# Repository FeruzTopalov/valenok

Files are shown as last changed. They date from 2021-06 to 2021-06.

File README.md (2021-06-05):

## **VALENOK** - yet another DS18B20 thermometer, but...

<p align="center">
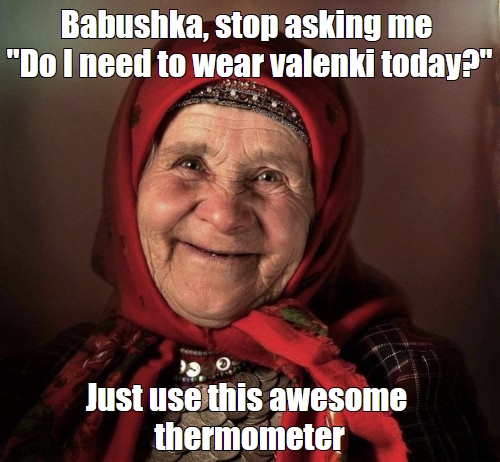
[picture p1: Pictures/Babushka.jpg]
  
  <br>
  <a href="https://youtu.be/WqwGhjjpDnw">https://youtu.be/WqwGhjjpDnw</a>
</p>

* Eyes-friendly static indication
* Zero-consumption when IDLE, years without battery replacement
* Single button interface
* Only temperature - who the f**k needs more?
* Totally open-source/open-hardware
* Easy solderable - 0805 chip components and huuuge SMD packages

## Hardware

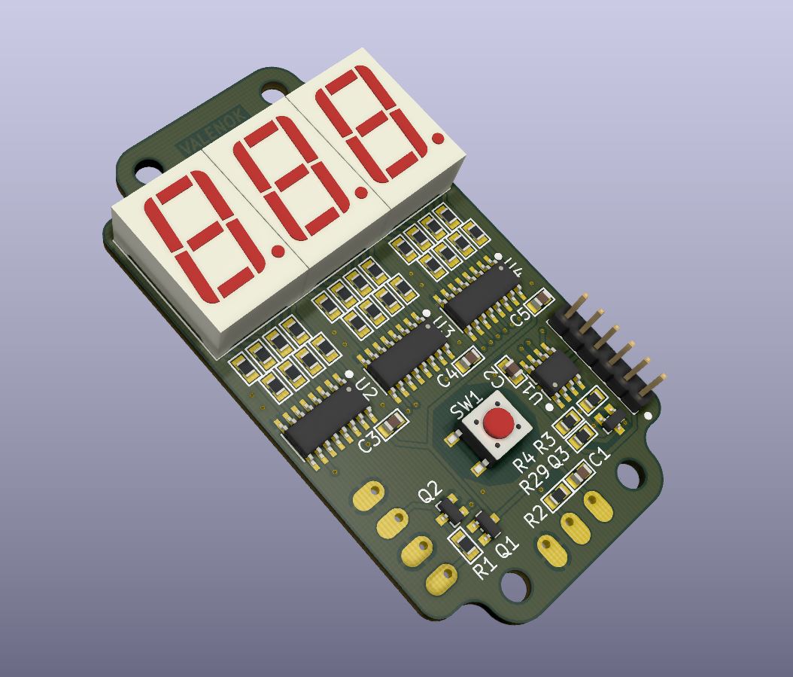
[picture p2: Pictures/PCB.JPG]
PCB


Well, it is a typical KiCad project, schematic + PCB. Also there are prepared gerbers, so if you don't want to deal with KiCad, just zip "gerbers" folder and send it to your PCB supplier. 

Schematic is pretty simple. Q1 and Q2 are power switch, which is controlled via MCU. Q3 is a "HC595 anti-glitch" which controls the sift registers state at power-up. By the way, switch SW1 powers on the thermometer, after that MCU holds Q2's gate until the end of the program.

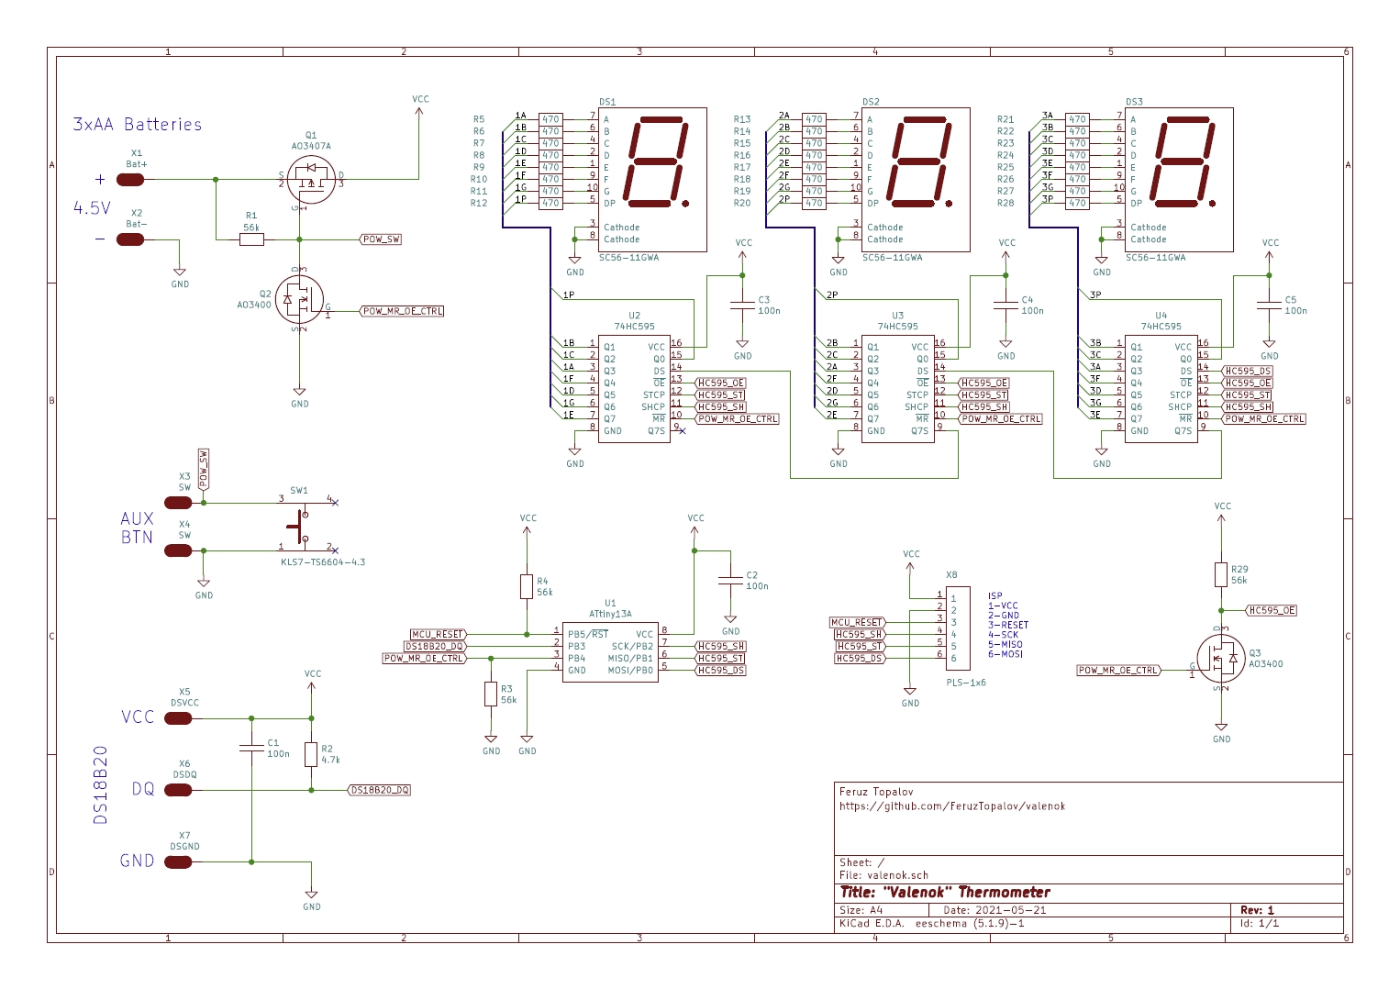
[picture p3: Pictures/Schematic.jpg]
Schematic


As you can see, power switch and shift registers are controlled using common pin PB4 (POW_MR_OE_CTRL). That trick is here in order to clear the shift registers (HC595) at startup. The algorithm is following:

* User pushes the SW1
* PB4 is low, power is not engaged by Q2
* OE is high due to inversion at the Q3, outputs of the shift registers are in Hi-Z
* MR is low, shift registers are cleared
* Firmware strikes a strobe to the shift registers ST inputs, the content of the shift registers (which are empty) are copied to the outputs
* Finally, MCU rise up PB4, engage the power switch and enables the shift registers outputs
* You see empty 7-seg display, no randomly blinking segments anymore... PROFIT!

_See 'Pictures/Trick.jpg' for details_

## Firmware

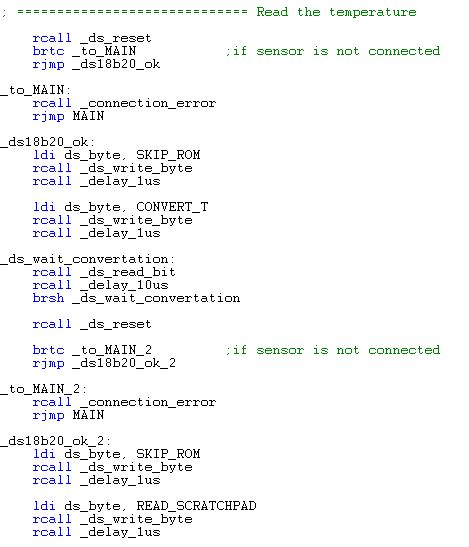
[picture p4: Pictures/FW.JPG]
FW


Written in assembler using pretty old AVR Studio 4.19, therefore i publish only the listing but not the project file. I you want to compile by yourself, use any appropriate AVR compiler or find AVR Studio 4.19 on the internet. Anyway there is a ready .hex file to flash.

Firmware flow:
* Clear HC595 registers
* Hold the power
* Blink all segments for 100 ms in order to check their functionality
* Check sensor presence, show "---" if not connected
* Read the temperature
* Calculate CRC, show "crc" if mismatch
* Check DS18B20 for 12-bit mode, if not then switch to 12-bit mode
* Perform temperature rounding +-0.5 Celsius degree
* Prepare display content and show
* Hold on for 3 sec
* Release the power

Flashing is also simple, the only thing you should aware is that you have to change fuse bits. Tiny13A's factory default fuses are LOW:0x6A; HIGH:0xFF. To make thermometer works it is only needed to switch off internal clock division by 8 (CKDIV8). Therefore only LOW fuse is affected, it's value changes from LOW:0x6A to LOW:0x7A - that simple. I recommend to use AVRDUDESS (https://github.com/zkemble/AVRDUDESS). 

## Enclosure

It is designed to be placed in a market available GAINTA G1068G/G1068B enclosure. It has dimensions of 95 x 48 x 38 mm. 

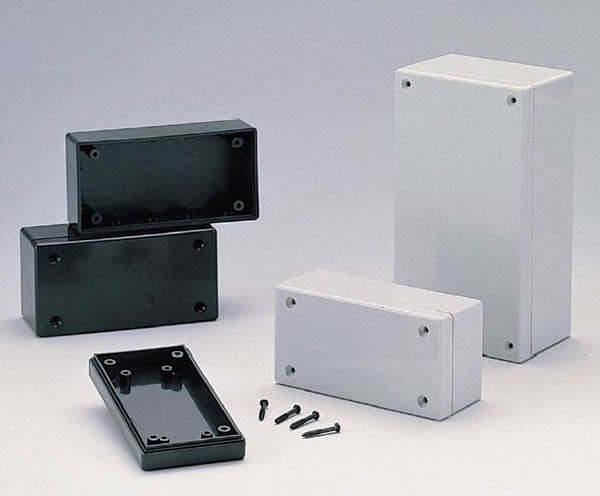
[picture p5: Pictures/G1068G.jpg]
Enclosure


PCB is fixed to the smaller lid using 20 mm Male-Female Hex standoffs; 3x AA batteries with no holder are placed underneath the PCB.

In "dxf" folder you can find a guide where to make holes - one for 7-Seg display, one for button:

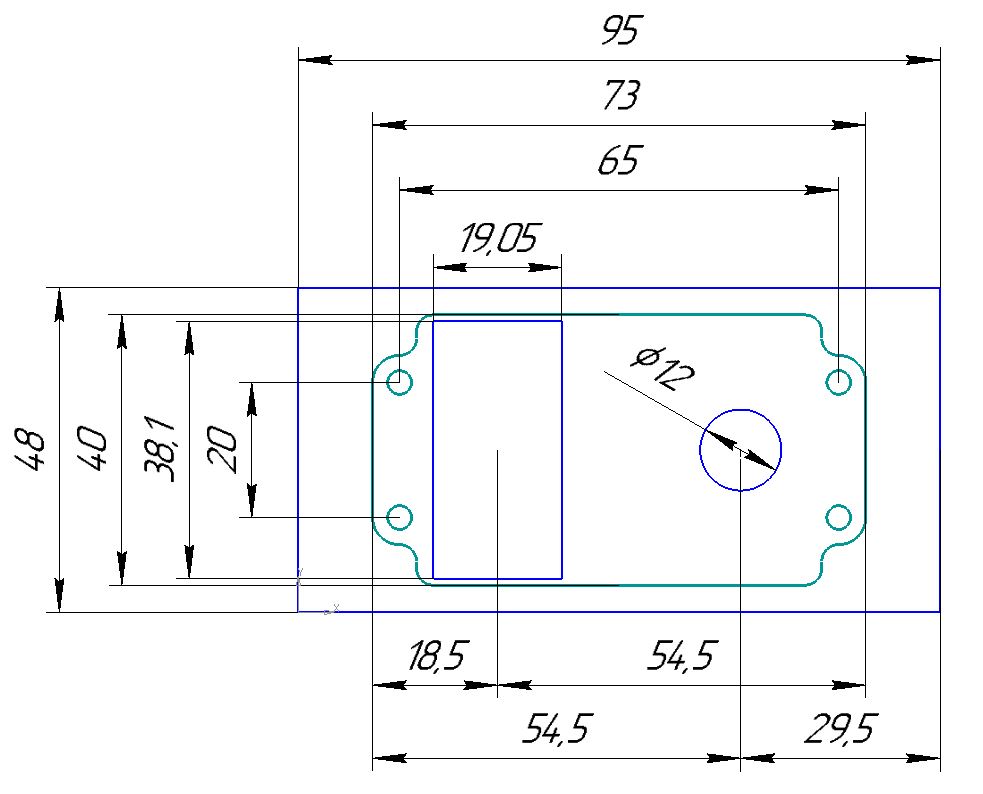
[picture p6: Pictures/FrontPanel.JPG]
Panel


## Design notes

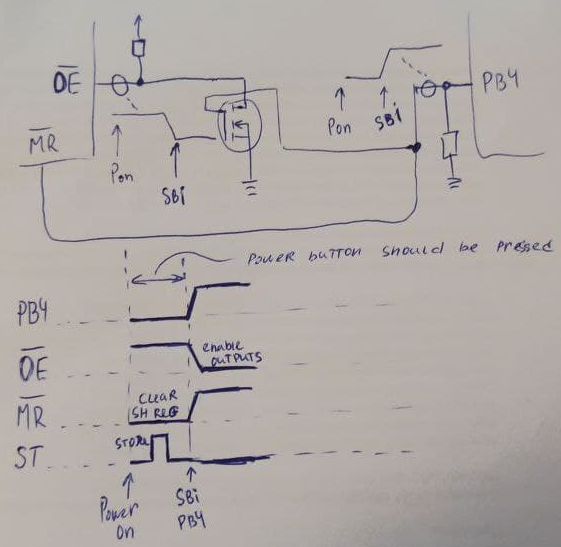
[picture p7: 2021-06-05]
Pictures/Trick.jpg

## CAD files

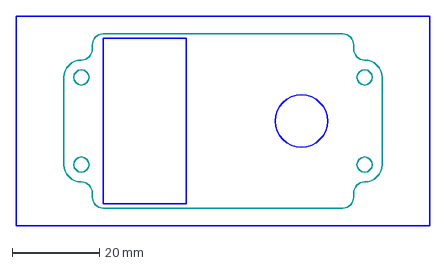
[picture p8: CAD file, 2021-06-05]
Hardware/dxf/PCB_over_front_panel.dxf
95.0 x 48.0 mm

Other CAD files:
Hardware/dxf/G1068B_G1068B.dwg

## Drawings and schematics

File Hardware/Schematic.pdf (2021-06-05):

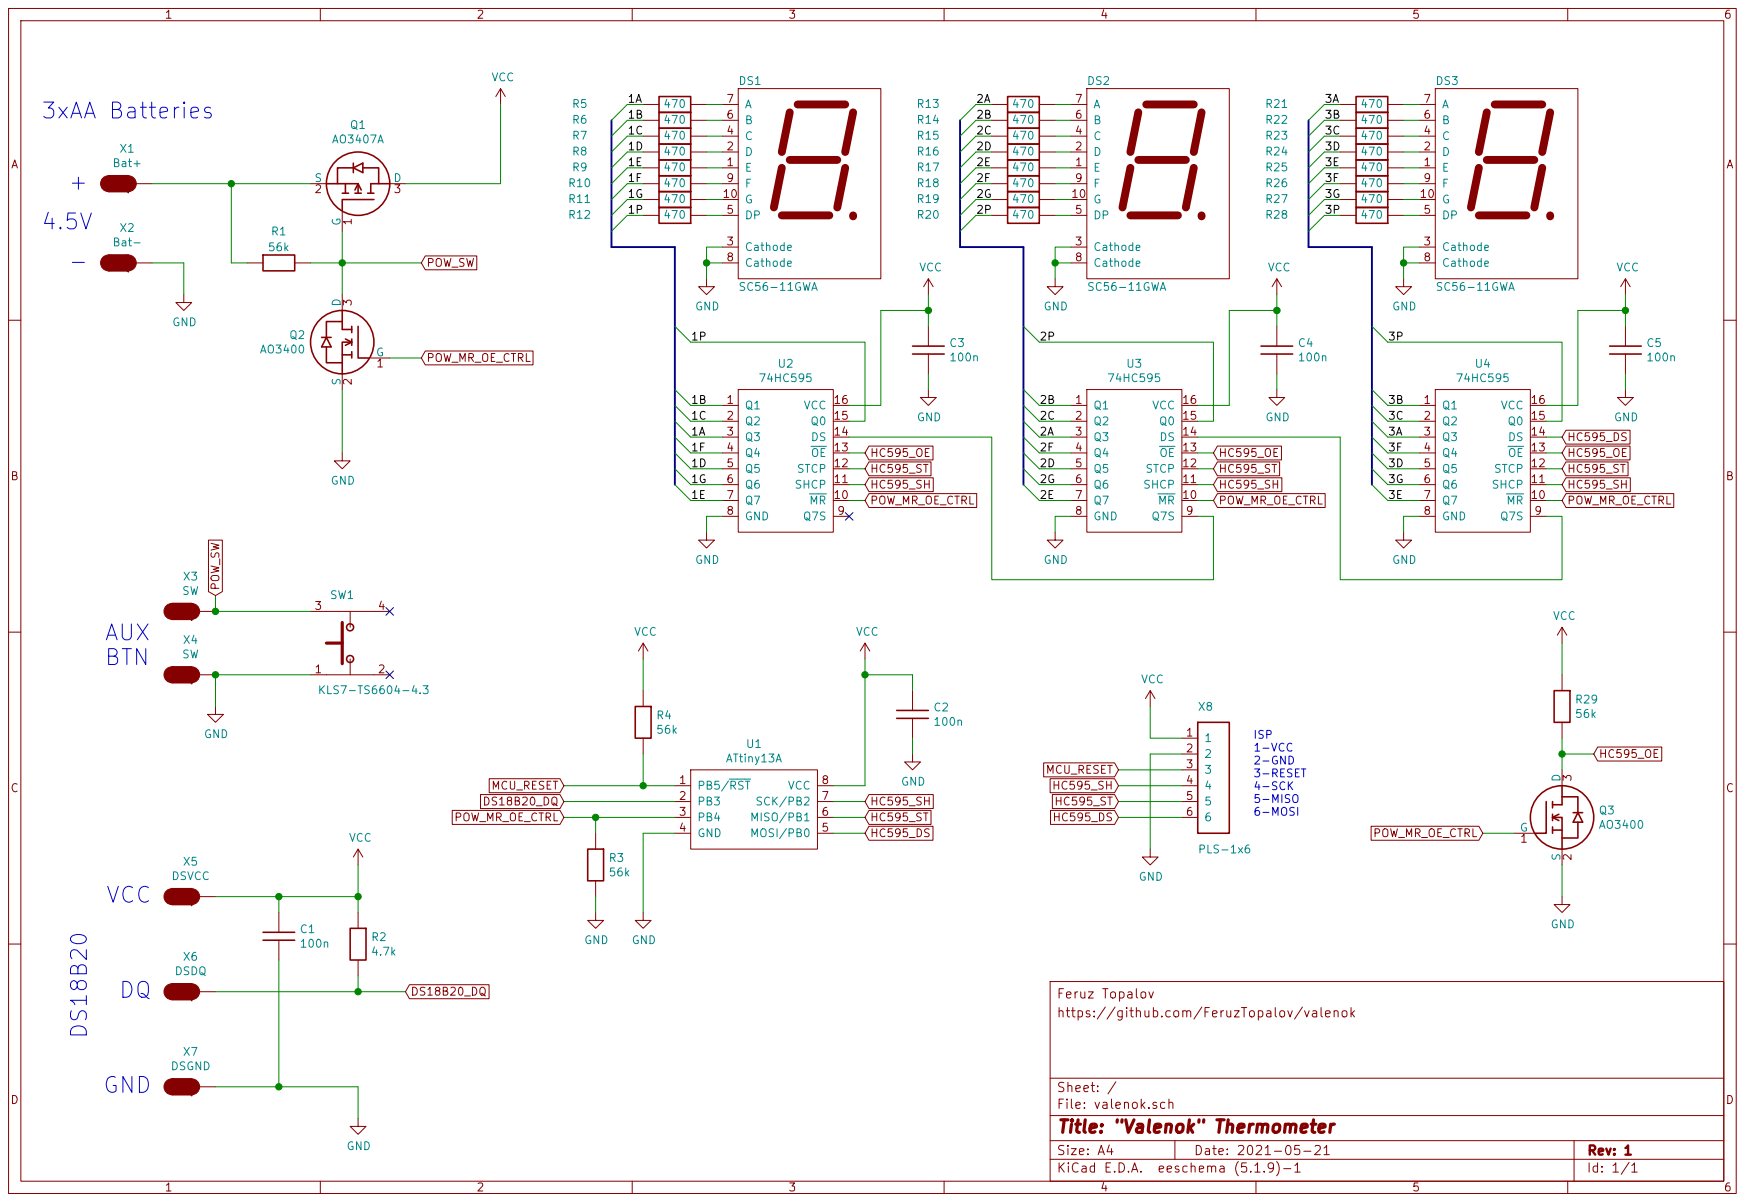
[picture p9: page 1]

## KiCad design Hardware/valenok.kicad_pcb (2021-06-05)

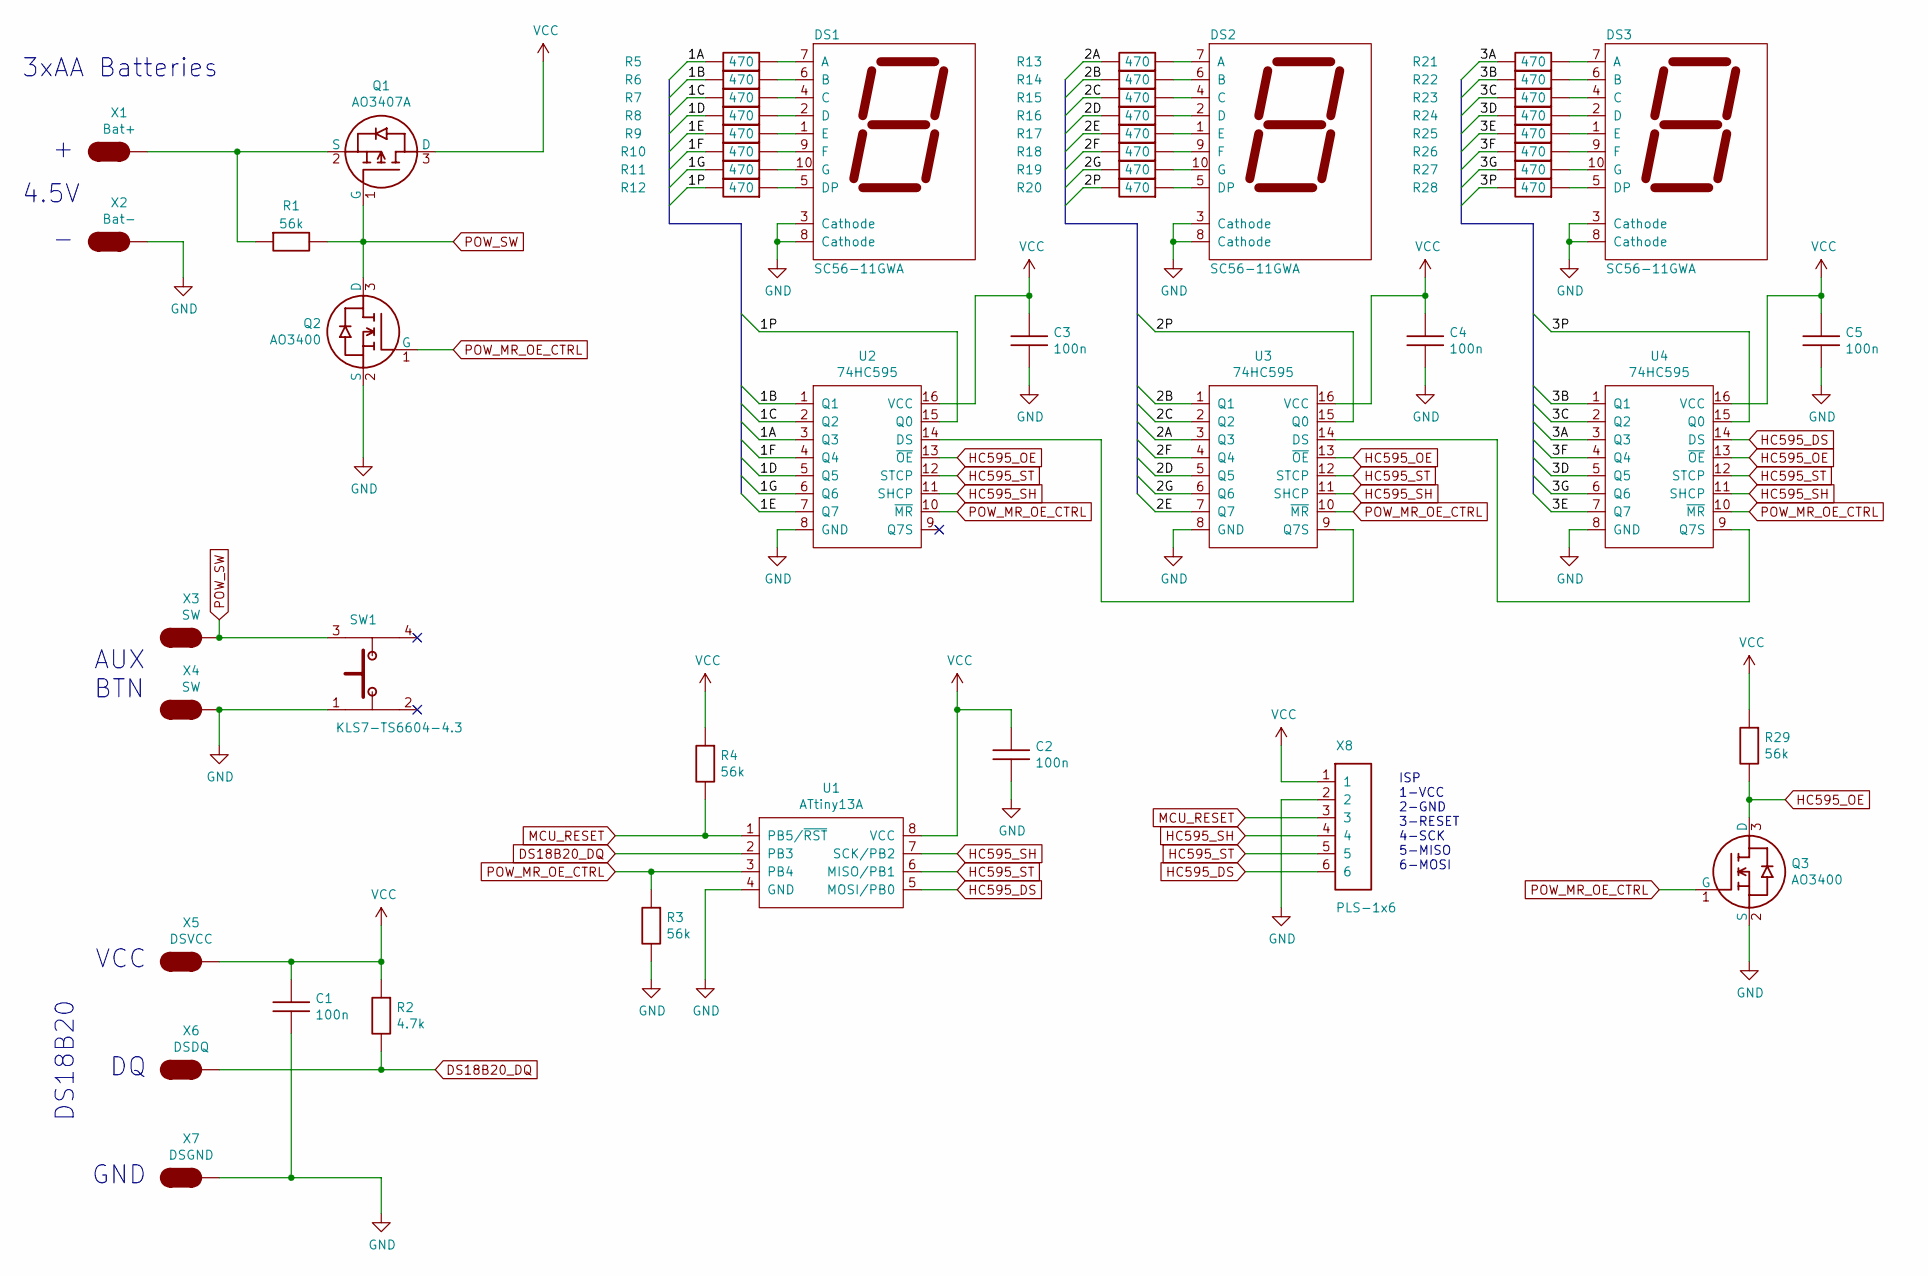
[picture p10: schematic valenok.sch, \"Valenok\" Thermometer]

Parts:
C1, C2, C3, C4, C5: 100n; C0805
DS1, DS2, DS3: SC56-11GWA; 7seg_0.56in
Q1: AO3407A; SOT-23
Q2, Q3: AO3400; SOT-23
R1, R3, R4, R29: 56k; R0805
R2: 4.7k; R0805
R5, R6, R7, R8, R9, R10, R11, R12, R13, R14, R15, R16, R17, R18, R19, R20, R21, R22, R23, R24, R25, R26, R27, R28: 470; R0805
SW1: KLS7-TS6604-4.3; 6x6switch
U1: ATtiny13A; SOIC-8
U2, U3, U4: 74HC595; SOIC-16
X1: Bat+; Pad
X2: Bat-; Pad
X3, X4: SW; Pad
X5: DSVCC; Pad
X6: DSDQ; Pad
X7: DSGND; Pad
X8: PLS-1x6; 1x6header

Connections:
/1A: R5.2, U2.3 (Q3)
/1B: R6.2, U2.1 (Q1)
/1C: R7.2, U2.2 (Q2)
/1D: R8.2, U2.5 (Q5)
/1E: R9.2, U2.7 (Q7)
/1F: R10.2, U2.4 (Q4)
/1G: R11.2, U2.6 (Q6)
/1P: R12.2, U2.15 (Q0)
/2A: R13.2, U3.3 (Q3)
/2B: R14.2, U3.1 (Q1)
/2C: R15.2, U3.2 (Q2)
/2D: R16.2, U3.5 (Q5)
/2E: R17.2, U3.7 (Q7)
/2F: R18.2, U3.4 (Q4)
/2G: R19.2, U3.6 (Q6)
/2P: R20.2, U3.15 (Q0)
/3A: R21.2, U4.3 (Q3)
/3B: R22.2, U4.1 (Q1)
/3C: R23.2, U4.2 (Q2)
/3D: R24.2, U4.5 (Q5)
/3E: R25.2, U4.7 (Q7)
/3F: R26.2, U4.4 (Q4)
/3G: R27.2, U4.6 (Q6)
/3P: R28.2, U4.15 (Q0)
DS18B20_DQ: R2.2, U1.2 (PB3), X6.1
GND: C1.2, C2.2, C3.2, C4.2, C5.2, DS1.3 (Cathode), DS1.8 (Cathode), DS2.3 (Cathode), DS2.8 (Cathode), DS3.3 (Cathode), DS3.8 (Cathode), Q2.2 (S), Q3.2 (S), R3.2, SW1.1, U1.4 (GND), U2.8 (GND), U3.8 (GND), U4.8 (GND), X2.1, X4.1, X7.1, X8.2
HC595_DS: U1.5 (MOSI/PB0), U4.14 (DS), X8.6
HC595_OE: Q3.3 (D), R29.2, U2.13 (~OE), U3.13 (~OE), U4.13 (~OE)
HC595_SH: U1.7 (SCK/PB2), U2.11 (SHCP), U3.11 (SHCP), U4.11 (SHCP), X8.4
HC595_ST: U1.6 (MISO/PB1), U2.12 (STCP), U3.12 (STCP), U4.12 (STCP), X8.5
MCU_RESET: R4.2, U1.1 (PB5/~RST), X8.3
unnamed: DS1.1 (E), R9.1
unnamed: DS1.2 (D), R8.1
unnamed: DS1.4 (C), R7.1
unnamed: DS1.5 (DP), R12.1
unnamed: DS1.6 (B), R6.1
unnamed: DS1.7 (A), R5.1
unnamed: DS1.9 (F), R10.1
unnamed: DS1.10 (G), R11.1
unnamed: DS2.1 (E), R17.1
unnamed: DS2.2 (D), R16.1
unnamed: DS2.4 (C), R15.1
unnamed: DS2.5 (DP), R20.1
unnamed: DS2.6 (B), R14.1
unnamed: DS2.7 (A), R13.1
unnamed: DS2.9 (F), R18.1
unnamed: DS2.10 (G), R19.1
unnamed: DS3.1 (E), R25.1
unnamed: DS3.2 (D), R24.1
unnamed: DS3.4 (C), R23.1
unnamed: DS3.5 (DP), R28.1
unnamed: DS3.6 (B), R22.1
unnamed: DS3.7 (A), R21.1
unnamed: DS3.9 (F), R26.1
unnamed: DS3.10 (G), R27.1
unnamed: Q1.2 (S), R1.1, X1.1
unnamed: U2.14 (DS), U3.9 (Q7S)
unnamed: U3.14 (DS), U4.9 (Q7S)
POW_MR_OE_CTRL: Q2.1 (G), Q3.1 (G), R3.1, U1.3 (PB4), U2.10 (~MR), U3.10 (~MR), U4.10 (~MR)
POW_SW: Q1.1 (G), Q2.3 (D), R1.2, SW1.3, X3.1
VCC: C1.1, C2.1, C3.1, C4.1, C5.1, Q1.3 (D), R2.1, R4.1, R29.1, U1.8 (VCC), U2.16 (VCC), U3.16 (VCC), U4.16 (VCC), X5.1, X8.1

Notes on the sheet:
4.5V
AUX BTN
DS18B20
GND
VCC
ISP 1-VCC 2-GND 3-RESET 4-SCK 5-MISO 6-MOSI
3xAA Batteries

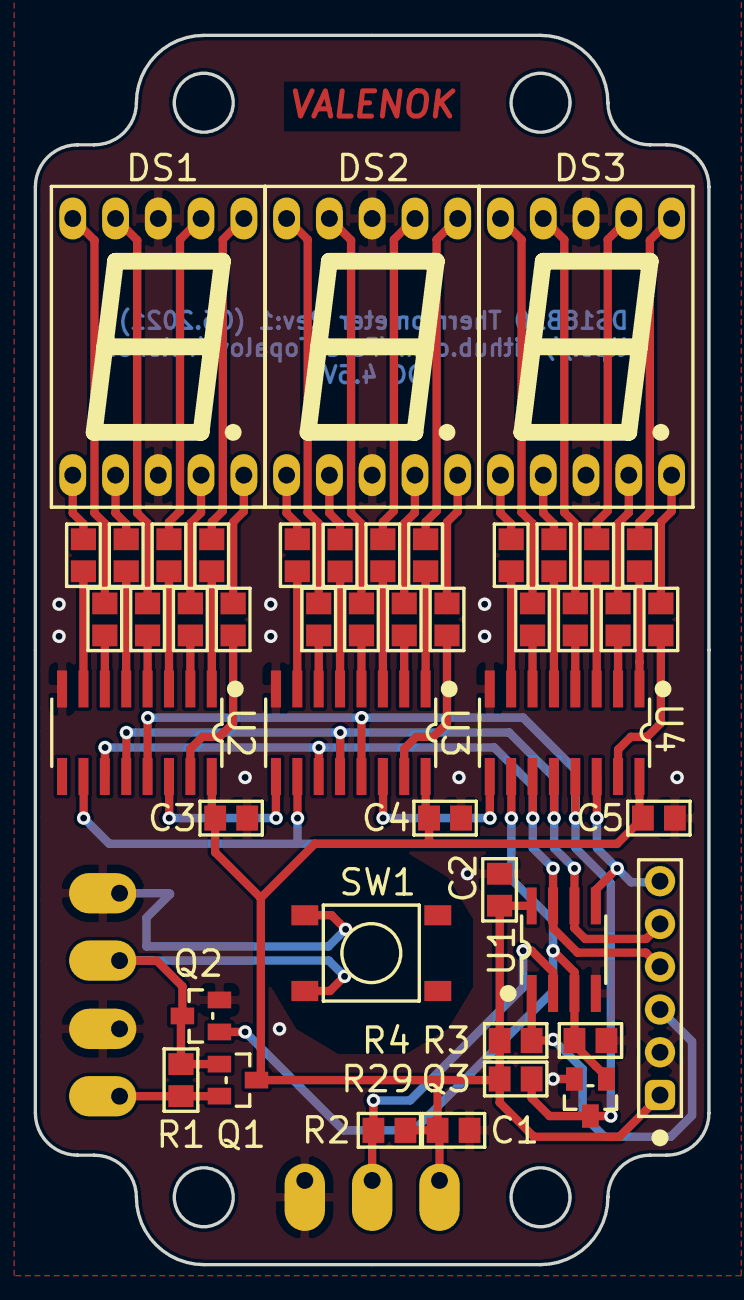
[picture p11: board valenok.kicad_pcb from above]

Board: 2 copper layers, 40.0 x 73.0 mm, 53 parts (0 on the bottom side), 61 nets.

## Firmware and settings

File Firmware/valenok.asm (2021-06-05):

;	Valenok - Simple and affordable DS18B20-based thermometer in a Gainta G1068G case written in AVR Assembly
;	<https://github.com/FeruzTopalov/valenok/>
;	Copyright (C) 2021 Feruz Topalov
;	Released under the GNU General Public License v3.0 <https://www.gnu.org/licenses/>
;    
;	File: valenok.asm
;	Compiler: AVR Studio 4.19
;	
;	Fuses for AVRDUDESS: LOW:0x7A; HIGH:0xFF (internal RC 9.6 MHz, no clock division)

						

; =============================	Include

.include  "tn13Adef.inc"

; =============================	DS18B20 macroses

	.macro m_pb3_input
		cbi DDRB, PB3
	.endm

	.macro m_pb3_output
		sbi DDRB, PB3
	.endm

	.macro m_pb3_hi
		sbi PORTB, PB3
	.endm

	.macro m_pb3_lo
		cbi PORTB, PB3		
	.endm

; =============================	Power & HC595 control macroses

	.macro m_pow_mr_oe_ctrl_hi
		sbi	PORTB, PB4
	.endm

	.macro m_pow_mr_oe_ctrl_lo
		cbi	PORTB, PB4
	.endm

; =============================	HC595 macroses

	.macro	m_sh_hi
		sbi	PORTB, PB2
	.endm

	.macro	m_sh_lo
		cbi	PORTB, PB2
	.endm

	.macro	m_ds_hi
		sbi	PORTB, PB0
	.endm

	.macro	m_ds_lo
		cbi	PORTB, PB0
	.endm

	.macro	m_st_hi
		sbi	PORTB, PB1
	.endm

	.macro	m_st_lo
		cbi	PORTB, PB1
	.endm

; =============================	Delay macroses

	.macro	set_delay			;set up the time delay amount, from 1 to 7
		subi	@0, (@1 << 5)	;NOTE: THIS shift affects INC macro (below)!
	.endm

	.macro	inc_delay			;bump the delay counter
		subi	@0, -(1 << 5)	;shift value here must be same as above!
	.endm

; =============================	Constants

	.equ symbol_minus = 0x40
	.equ symbol_degree = 0x5A
	.equ symbol_dot = 0x01
	.equ symbol_c = 0xE0
	.equ symbol_r = 0xC0	
	.equ crc_polynom = 0x8C
	.equ config_reg_12bit = 0x7F	

; =============================	DS18B20 Commands

	.equ SKIP_ROM = 0xCC
	.equ CONVERT_T = 0x44
	.equ READ_SCRATCHPAD = 0xBE
	.equ WRITE_SCRATCHPAD = 0x4E
	.equ COPY_SCRATCHPAD = 0x48

; =============================	Registers

	.def count_bytes = R0
	.def count_bits = R1
	.def crc_polynom_calc = R2

	.def fract = R15
	.def temp = R16	

	;R17-R19 - delay routines

	.def ds_byte = R20
	.def i = R21

	.def _r1 = R22 ;Left digit
	.def _r2 = R23 ;Center digit
	.def _r3 = R24 ;Right digit

	.def data = R25	

	;R26-R27 - XH:XL

	.def CRC = R28 		;crc
	.def CRC_next = R29 ;crc next byte

	.def Tlsb = R28		;temperature
	.def Tmsb = R29		;multiple declaration in sake of convenience

	;R30-R31 - ZH:ZL

; =============================	Code segment

	.cseg
	.org 0

; =============================	Interrupts

rjmp START  ; RESET
	reti	; EXT_INT0
	reti    ; PCINT0
	reti    ; TIMER0_OVF
	reti    ; EE_RDY
	reti    ; ANA_COMP
	reti    ; TIMER0_COMPA
	reti    ; TIMER0_COMPA
	reti	; WTD
	reti 	; ADC


; =============================	Program starts here

START:

; =============================	Init stack and ports

	ldi temp, low(RAMEND)
	out SPL, temp
	
	ldi temp, (0<<DDB5)|(1<<DDB4)|(0<<DDB3)|(1<<DDB2)|(1<<DDB1)|(1<<DDB0)	;i/o direction
	out DDRB, temp
	nop

	ldi temp, (0<<PB5)|(0<<PB4)|(0<<PB3)|(0<<PB2)|(0<<PB1)|(0<<PB0)			;level/pull-up
	out PORTB, temp
	nop

; =============================	Clear the HC595 registers

	rcall _delay_100us
	rcall _HC595_store
	rcall _delay_100us

; =============================	Hold the power

	m_pow_mr_oe_ctrl_hi

; =============================	Check the 7-seg indicators

	ldi data, 0xFF
	rcall _HC595_load
	ldi data, 0xFF
	rcall _HC595_load
	ldi data, 0xFF
	rcall _HC595_load
	rcall _HC595_store

	rcall _delay_100ms

	ldi data, 0x00
	rcall _HC595_load
	ldi data, 0x00
	rcall _HC595_load
	ldi data, 0x00
	rcall _HC595_load
	rcall _HC595_store

; ============================= Read the temperature

	rcall _ds_reset
	brtc _to_MAIN			;if sensor is not connected
	rjmp _ds18b20_ok

_to_MAIN:
	rcall _connection_error
	rjmp MAIN

_ds18b20_ok:
	ldi ds_byte, SKIP_ROM
	rcall _ds_write_byte
	rcall _delay_1us

	ldi ds_byte, CONVERT_T
	rcall _ds_write_byte
	rcall _delay_1us

_ds_wait_convertation:
	rcall _ds_read_bit
	rcall _delay_10us
	brsh _ds_wait_convertation

	rcall _ds_reset

	brtc _to_MAIN_2			;if sensor is not connected
	rjmp _ds18b20_ok_2

_to_MAIN_2:
	rcall _connection_error
	rjmp MAIN

_ds18b20_ok_2:
	ldi ds_byte, SKIP_ROM
	rcall _ds_write_byte
	rcall _delay_1us

	ldi ds_byte, READ_SCRATCHPAD
	rcall _ds_write_byte
	rcall _delay_1us

; ============================= Copy sensor's scratchpad into MCU RAM

	ldi XL, Low(SRAM_START)
	ldi XH, High(SRAM_START)

	ldi temp, 9
_read_scratchpad:
	
	rcall _ds_read_byte
	rcall _delay_1us	
	
	st X+, ds_byte

	dec temp
	brne _read_scratchpad

; ============================= Calculate CRC

	ldi temp, crc_polynom
	mov crc_polynom_calc, temp

	ldi XL, Low(SRAM_START)
	ldi XH, High(SRAM_START) 
	ld CRC, X+

	ldi temp, 8
	mov count_bytes, temp
_loop_bytes:
	ld CRC_next, X+

	ldi temp, 8
	mov count_bits, temp
_loop_bits:
	lsr CRC_next
	ror CRC
	brcc _zero
	eor CRC, crc_polynom_calc
_zero:
	dec count_bits
	brne _loop_bits

	dec count_bytes
	brne _loop_bytes

	cpi CRC, 0 
	brne _crc_error
	rjmp _crc_ok

_crc_error:
	ldi data, symbol_c		;"crc" Error message if CRC mismatch
	rcall _HC595_load
	ldi data, symbol_r
	rcall _HC595_load
	ldi data, symbol_c
	rcall _HC595_load
	rcall _HC595_store	
	rjmp MAIN

_crc_ok:					;restore two bytes of the temperature from MCU RAM
	ldi XL, Low(SRAM_START)
	ldi XH, High(SRAM_START) 
	ld Tlsb, X+				;now temterature is here
	ld Tmsb, X

; ============================= Check for 12-bit mode

	ldi XL, Low(SRAM_START + 4)		;points to ds18b20 configuration register
	ldi XH, High(SRAM_START + 4)
	ld temp, X
	cpi temp, config_reg_12bit
	breq _skip_forced_12bit

	rcall _ds_reset

	ldi ds_byte, SKIP_ROM
	rcall _ds_write_byte	

	ldi ds_byte, WRITE_SCRATCHPAD
	rcall _ds_write_byte

	ldi ds_byte, 0x00				;TH & TL registers
	rcall _ds_write_byte
	rcall _ds_write_byte

	ldi ds_byte, config_reg_12bit
	rcall _ds_write_byte
	
	rcall _ds_reset

	ldi ds_byte, SKIP_ROM
	rcall _ds_write_byte

	ldi ds_byte, COPY_SCRATCHPAD
	rcall _ds_write_byte
	
	rcall _delay_100ms

; ============================= Convert temperature format and perform rounding +-0.5 deg C

_skip_forced_12bit:
	mov fract, Tlsb 	;save frac part
	ldi temp, 0x0F
	and fract, temp

	andi Tlsb, 0xF0 	;abs of the temperature
	andi Tmsb, 0x0F
	or Tlsb, Tmsb
	swap Tlsb

	mov temp, Tlsb 		;check for negative
	andi temp, 0x80
	brne _negative_temperature
	ldi Tmsb, 0x00 		;if positive

	mov temp, fract
	cpi temp, 0x08
	brlo _bcd 			;if frac < 0.5 then round down
	inc Tlsb 			;if frac >= 0.5 then round up
	rjmp _bcd

_negative_temperature:
	ldi Tmsb, 0xFF 		;if negative

	mov temp, fract
	cpi temp, 0x08 		;compare frac with 0.5
	brlo _05 			;if frac < 0.5 then convert from two's complement and increent
	com Tlsb 			;if frac >= 0.5 then convert from two's complement

	cpi Tlsb, 0			;check for "negative zero"
	brne _bcd
	ldi Tmsb, 0x00 		;make positive zero

	rjmp _bcd

_05:
	com Tlsb
	inc Tlsb
				
; =============================	Convert ot BCD

_bcd:
	push Tlsb
	ldi _r1, 0
	ldi _r2, 0
	ldi _r3, 0
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
